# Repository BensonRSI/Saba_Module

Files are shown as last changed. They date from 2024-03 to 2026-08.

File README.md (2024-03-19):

# Saba_Module
Replacement for a game -module for the SABA Videoplay console

SABA Videoplay is a gaming console connected to a TV-set from the mid 1970s 
( also know as "The Channel F" (initially named Fairchild Video Entertainment System) )
see : https://channelf.se/veswiki/index.php?title=Main_Page or 
https://en.wikipedia.org/wiki/Fairchild_Channel_F

The replacement module consist of a Raspberry RP2040 microcontroller ( + a levelshifter for 3.3 / 5 V conversion ) 
that emulates an F3851 adressdecoder IC and holds the ROMs and additional RAM for the programms.

It samples the module extension port on a high rate and implements the statemachine, that will do the generation of the programm-counter and adress-generator.
To archieve a high sample-speed these parts arm written in ARM assembler ( thumb ) and running exclusivly on core 1

The first core does some convenience functions. You can connect through the USB-line, with a serial terminal on 115200 and get a little menu to 
diplay the memory, load different ROMs from the build-in flash or upload ROMs with xmodem-protocol.

## How to build

Using vscode, you can either use a codespace on github or use "reopen in container" , which wil install all neccessary tools and submodules.

Open a new terminal and simply type "make" . This is a wrapper to call the cmake and build the binary.

## How to download

connect an USB-cable. Enter Firmware upload by holding the button when connecting.

type "make go" this will build and upload the firmware.

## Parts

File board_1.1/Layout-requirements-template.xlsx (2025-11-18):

XXXX Project - PCB Layout Requirements
PCB Thickness (Default value:1.6mm) |  |  | Component Sides (Top/Bottom/Both sides) |  |  | These parameters are required if using impedance control or ordering a high-power PCB
PCB Layer Count |  |  | PCB Dimensions
Inner Layer Copper Weight |  |  | Outer Layer Copper Weight
Desired EDA Software (Rec: EasyEDAPro) |  |  | Software Version
Power Capacity | Net Name | Voltage (V) | Current (A) | Comment |  | Mandatory. Trace widths and spacings are chosen taking into account the voltage and current capacity requirements.
Impedance Control (Single-Ended) | Net Name |  | Impedance |  | Comment | Optional. Specify which nets need impedance control and their respective impedance targets.
Impedance Control (Differential) | Net Name |  | Impedance |  | Comment
Comments
Silkscreen Information |  | Font Size |  | Comment

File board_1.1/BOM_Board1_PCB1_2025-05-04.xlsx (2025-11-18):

No. | Quantity | Comment | Designator | Footprint | Value | Manufacturer Part | Manufacturer | Supplier Part | Supplier
1 | 1 | BAT20JFILM | D1 | SOD-323_L1.8-W1.3-LS2.5-RD |  | BAT20JFILM | ST(意法半导体) | C155590 | LCSC
2 | 1 | CSCC118-0602A002C1AC | H1 | HDR-SMD_6P-P1.00-V-F-S2.9_1 |  | CSCC118-0602A002C1AC | GREENCONN(格康) | C7434515 | LCSC
3 | 1 | 330Ω | R1 | R0805 | 330Ω | WR08X331JTL | Walsin(华新科) | C163990 | LCSC
4 | 1 | 3.3kΩ | R2 | R0805 | 3.3kΩ | WR08X332JTL | Walsin(华新科) | C163986 | LCSC
5 | 1 | RP2040-Plus | U1 | LCC-40_L51.0-W21.0-P2.54-BL_RP2040-BASED |  | RP2040-Plus | Waveshare(微雪电子) | C5374681 | LCSC
6 | 1 | SN74LVC16245ADGGR | U2 | TSSOP-48_L12.6-W6.2-P0.50-LS8.1-BL |  | SN74LVC16245ADGGR | TI(德州仪器) | C7824 | LCSC

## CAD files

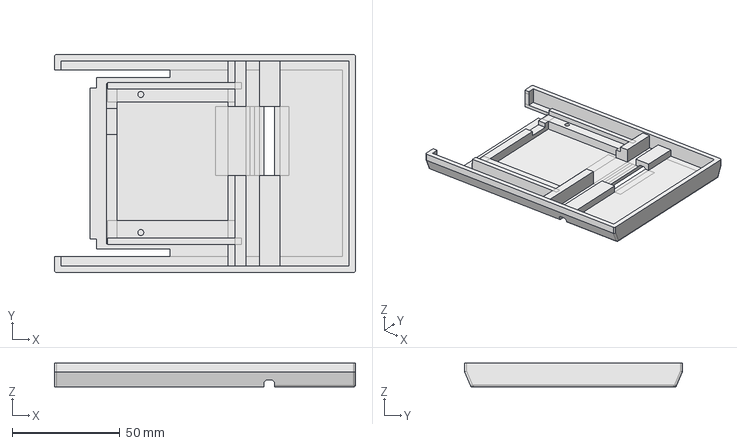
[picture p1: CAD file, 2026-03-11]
case/Case_unten_v3.FCStd
139.5 x 101.0 x 11.1 mm

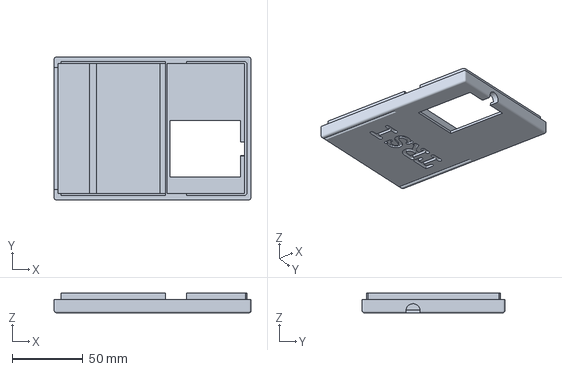
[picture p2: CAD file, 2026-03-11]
case/Case_oben_v2-Chamfer.3mf
139.5 x 101.0 x 14.0 mm

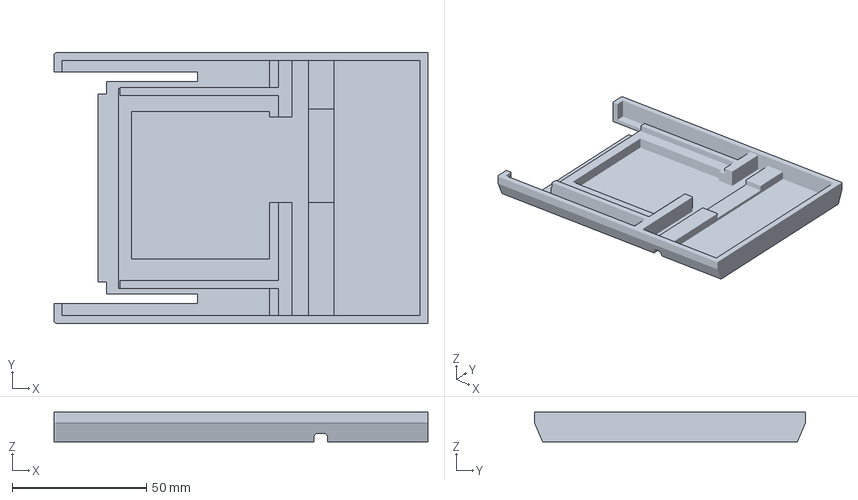
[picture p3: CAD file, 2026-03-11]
case/Case_unten_v2-Fillet001.3mf
139.5 x 101.0 x 11.1 mm

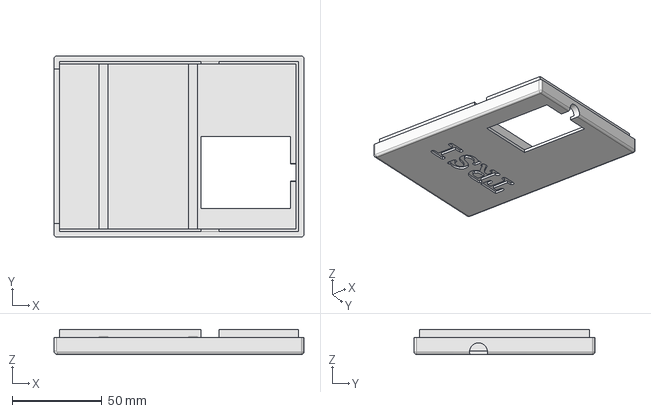
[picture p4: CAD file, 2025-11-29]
case/Case_oben.FCStd
139.5 x 101.0 x 14.0 mm

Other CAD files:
case/Case_oben-Fusion002.3mf
case/Case_unten-Cut003.3mf
case/Case_oben-Cut005.3mf
case/Case_unten_v2.FCStd
case/Case_unten.FCStd
case/Case_unten-Fillet001.3mf

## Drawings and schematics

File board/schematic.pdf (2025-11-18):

2DIR 24 2OE# 25 2A8 26 2A7 27 GND 28 2A6 29 2A5 30 VCC 31 2A4 32 2A3 33 GND 34 2A2 35 2A1 36 1A8 37 1A7 38 GND 39 1A6 40 1A5 41 VCC 42 1A4 43 1A3 44 GND 45 1A2 46 1A1 47 1OE# 48

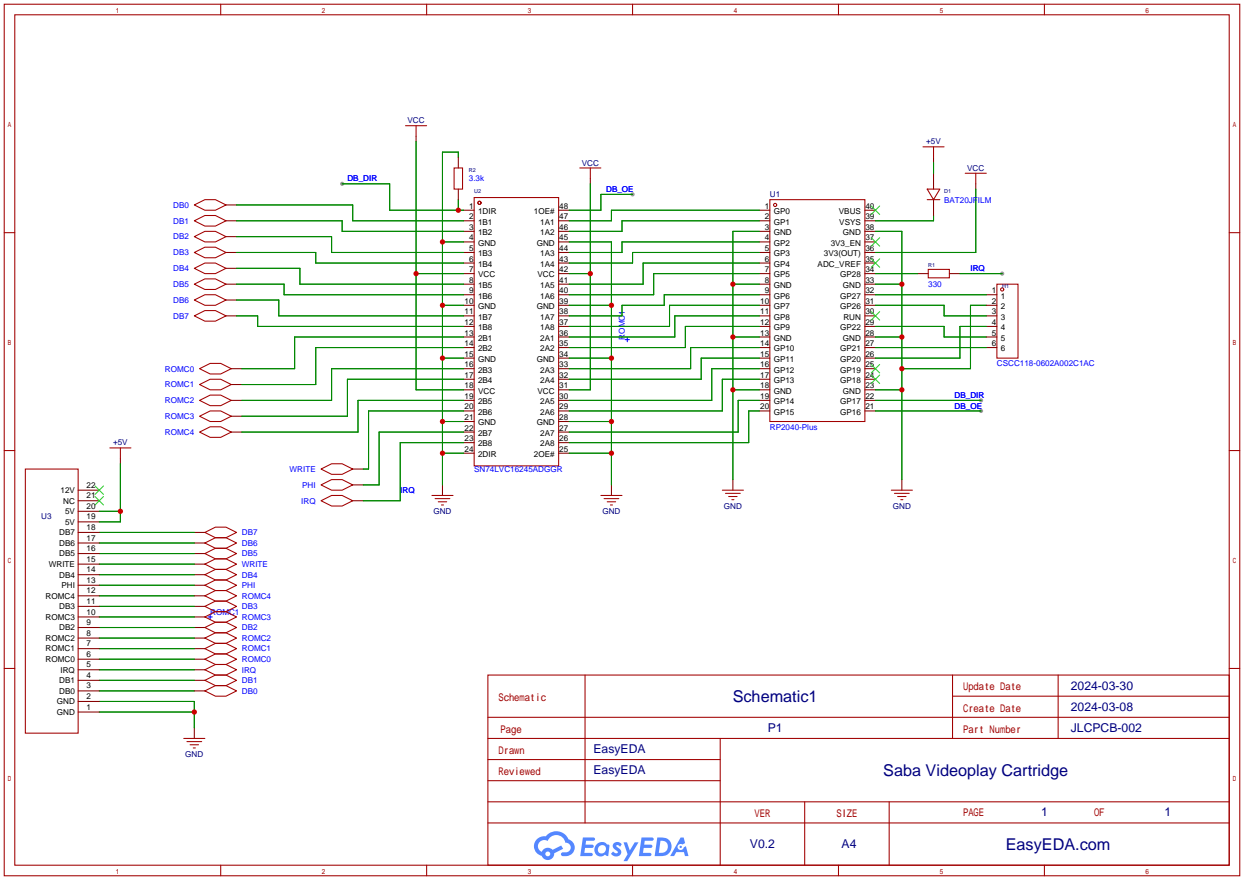
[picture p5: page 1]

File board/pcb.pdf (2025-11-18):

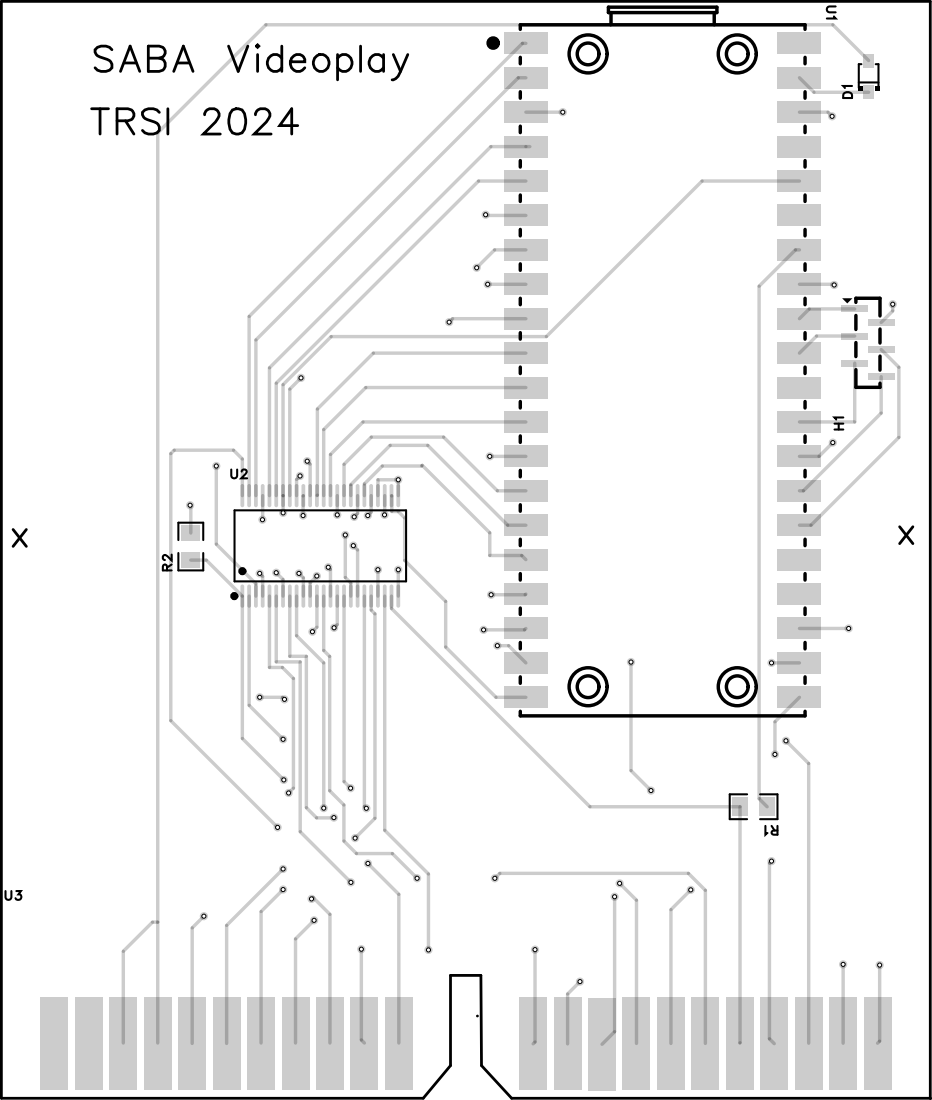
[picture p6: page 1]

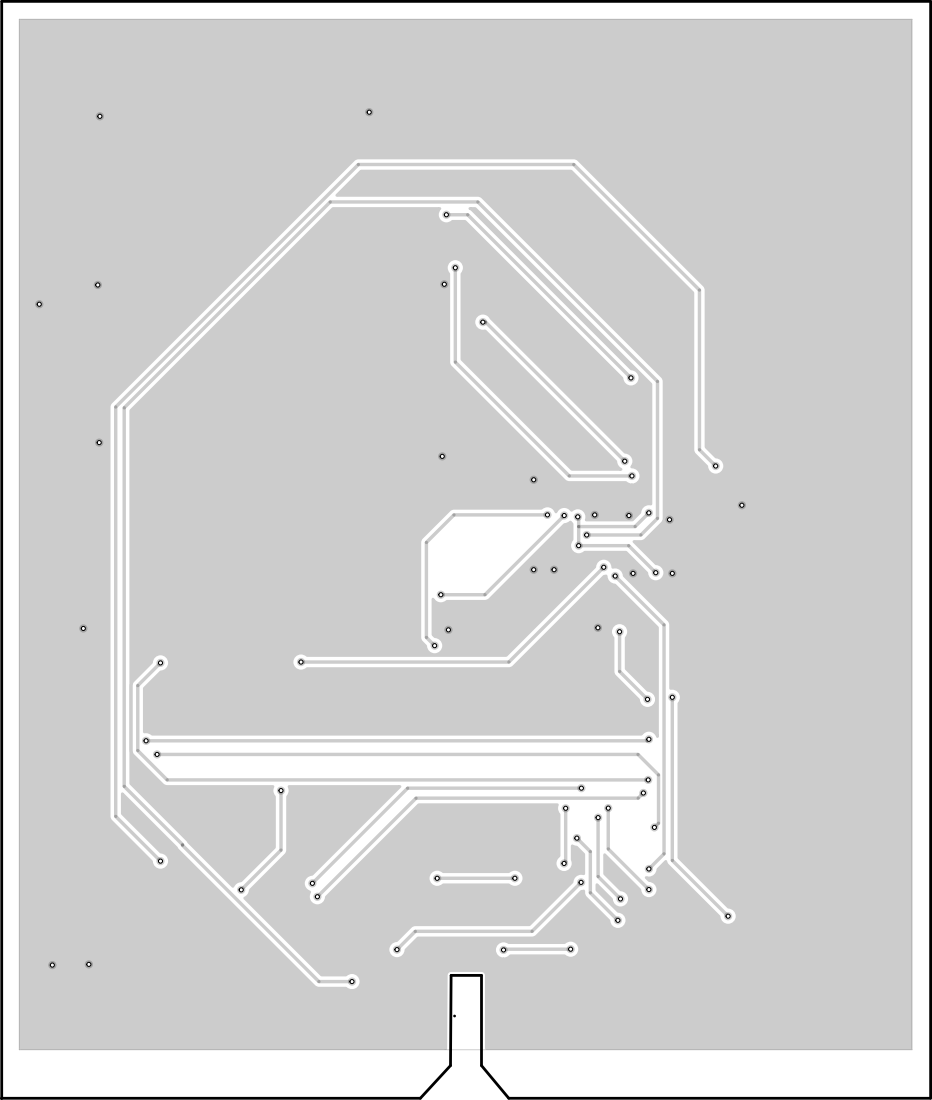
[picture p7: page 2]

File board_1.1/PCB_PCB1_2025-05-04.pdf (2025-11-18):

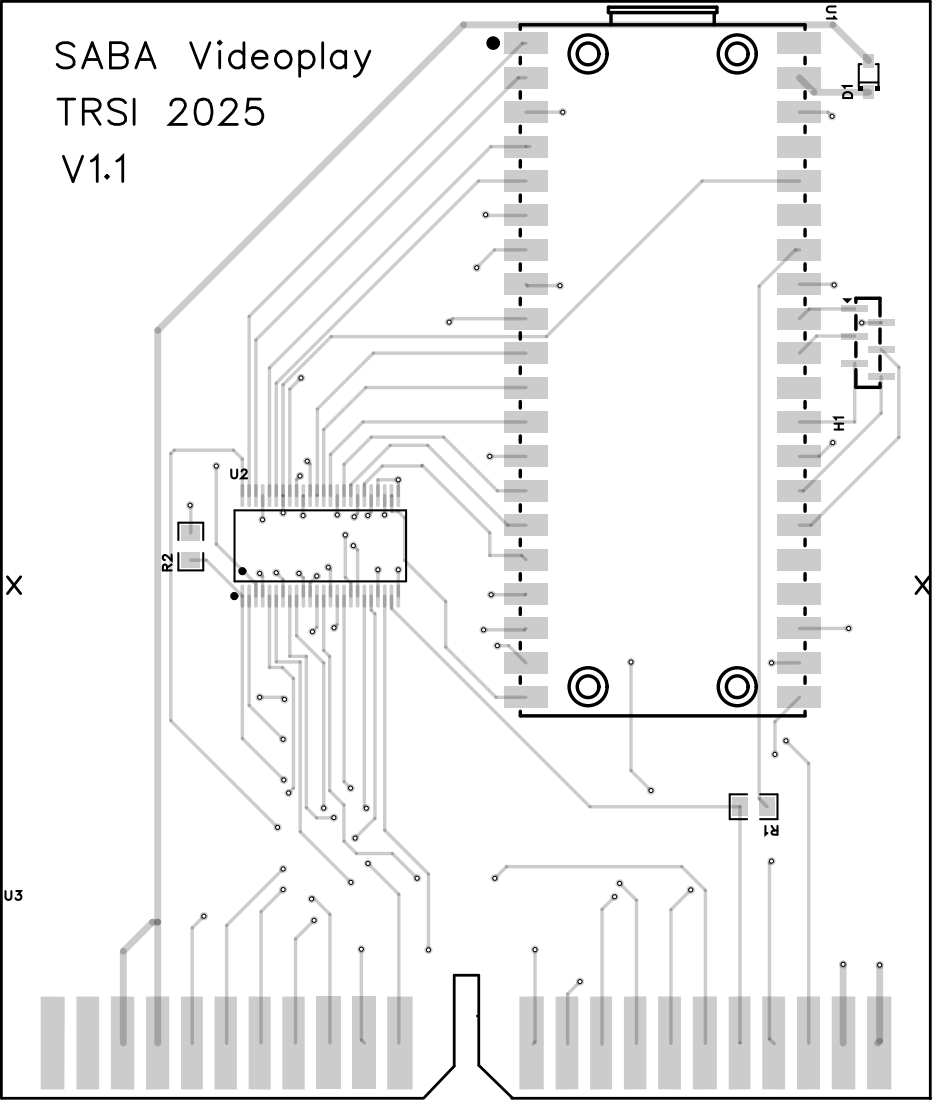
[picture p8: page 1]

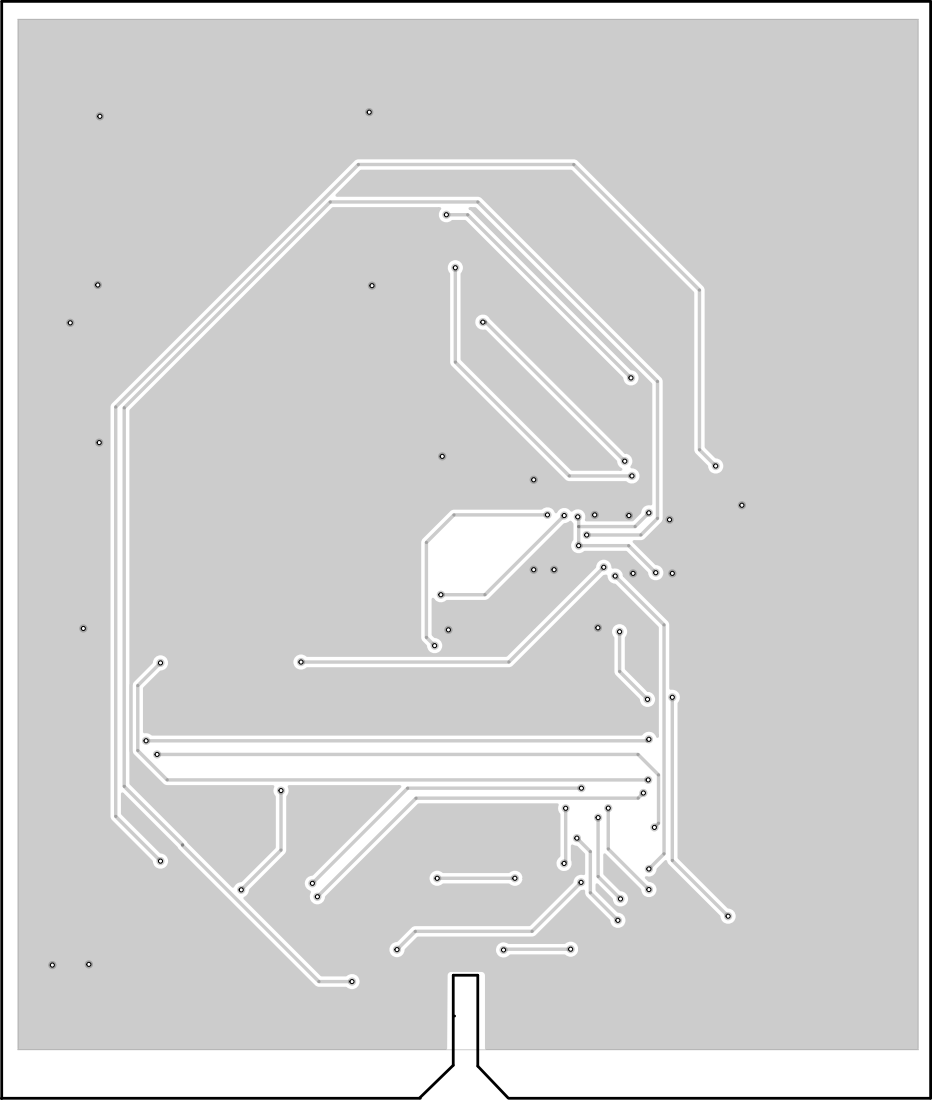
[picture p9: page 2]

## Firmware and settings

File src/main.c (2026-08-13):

/**
 * Copyright (c) 2024 Benson ( Olli )
 * SPDX-License-Identifier: GPL-3.0-or-later
 *
 *  This is part of the Saba_Module replacement for the Saba Videoplay console
 */

#include <time.h>
#include <stdio.h>
#include <ctype.h>
#include <string.h>

// #include "rp2040_purple.h"
#include <pico/stdlib.h>
#include <pico/util/queue.h>
#include <pico/multicore.h>
#include <pico/platform.h>
#include <pico/binary_info.h>
#include <hardware/vreg.h>   // Voltage control for overclocking
#include <hardware/clocks.h> // Clock control for overclocking

#include "bus.h"
#include "common.h"
#include "flash_store.h"

int main()
{
   // setup UART
   stdio_init_all();
   console_set_crlf(true);

#if 1
   // give some time to connect to console
   sleep_ms(2000);
#endif

#if 0
   vreg_set_voltage(VREG_VOLTAGE_1_30);
   sleep_ms(1);
   if (!(SET_CLOCK_FAST))
   { // 428000 is known to work on some devices
      // blink_code(BLINK::OVERCLOCK_FAILED);
      //     //panic("Overclock was unsuccessful");
      while (1)
         ;
   }
#endif
   // for toying with overclocking
   set_sys_clock_khz(133000, true); // 133 MHz is known to work on some devices

   // setup the bus and run the bus core
   multicore_launch_core1(bus_run);

   // run interactive console -> should never return
   console_run();

   return 0;
}

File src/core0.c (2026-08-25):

/**
 * Copyright (c) 2024 Benson ( Olli )
 * SPDX-License-Identifier: GPL-3.0-or-later
 *
 *  This is part of the Saba_Module replacement for the Saba Videoplay console
 */

#include <ctype.h>
#include <stdbool.h>
#include <stdio.h>
#include <string.h>
#include <stdint.h>
#include <stdlib.h>

#include <pico/multicore.h>
#include <pico/stdlib.h>
#include <pico/util/queue.h>
#include <hardware/clocks.h>

#include "common.h"
#include "getaline.h"
#include "mcurses.h"
#include "hexedit.h"
#include "bus.h"
#include "demo.h" // default demo data
#include "xmodem.h"
#include "flash_store.h"

// #define TEST_PATTERN // Fill memory with test pattern instead of 0x00

extern uint8_t memory[EMULATED_MEMSIZE]; // 64 k for Rom + 64 k banked Rom
// the first 32 bytes of the memory are used as IO-Ports
// The addresses are used for timer and IRQ-control and bank switching
// bit0-3 : IRQ control: 00=disable, 01=enable timer IRQ, others reserved
// bit4: timer start/stop
#define ICR_OFFSET_ADR 0xa
#define IRQ_CTRL_DISABLE 0
#define IRQ_CTRL_MASK 0x03 // for further use ,bit 1+2
#define IRQ_CTRL_ENABLE_TIMER_IRQ 3
#define IRQ_CTRL_ENABLE_EXT_IRQ 2

// this defines a 8-bit timer val, running at 38400 Hz
// with a prescaler od 31 , so 1 timer tick is 26 us *31
// a value of 0xff means timer stopped
// with a maximum Timer Tick of 0xfe, this means a maximum timer value of 0xfe * 806 = 204.724 us = 204 ms

#define IRQ_VECTOR_LOW_ADR 0x8
#define IRQ_VECTOR_HI_ADR 0x9
#define TIMER_VAL_ADR 0xb
#define ROM_BANK_ADR 0xc
#define TIMER_STOP 0xff
#define TIMER_CLOCK_MULTIPLIER 806 // 38400 Hz timer clock * 31  , so 1 timer tick = 806 us

extern volatile uint8_t reset_triggered;
extern volatile uint8_t irq_triggered;

uint8_t current_bank;
uint8_t upload_memory[0x10000 - 0x800 + BANK_SIZE * EXTENSION_BANKS]; /* Maximum size we can use = 64 k +62k*/
uint8_t *shadow_rom = &upload_memory[BANK_START_ADDRESS];             /* Shadow copy of the ROM when bank switching*/
#ifdef DEBUG_STATES
extern volatile uint8_t debug_val[18000];
int trace_dump = 0;
uint16_t print_buffer[2000];
#endif

bool console_crlf_enabled;
void debug_clocks();

// default functions are RAM access functons by pointers
uint8_t peekModuleMemory(uint16_t address)
{
   uint8_t *p;
   return memory[address];
}
void pokeModuleMemory(uint16_t address, uint8_t value)
{
   uint8_t *p;
   memory[address] = value;
}

uint8_t (*FunctionPointer_readModuleMemory)(uint16_t address) = peekModuleMemory;              // set default function
void (*FunctionPointer_writeModuleMemory)(uint16_t address, uint8_t value) = pokeModuleMemory; // set default function

/* For xmodem receive, we need to provide the HW specific functions*/
int _inbyte(int msec)
{

   int c = getchar_timeout_us(msec * 1000);
   if (c == PICO_ERROR_TIMEOUT)
   {
      return -1;
   }
   return c;
}
void _outbyte(unsigned char c)
{

   putchar(c);
}

void console_set_crlf(bool enable)
{
   uart_set_translate_crlf(uart0, enable);
   console_crlf_enabled = enable;
}

void fill_ram(uint8_t val)
{
#ifndef TEST_PATTERN
   memset(memory, val, EMULATED_MEMSIZE);
#else
   for (uint32_t i = 0; i < EMULATED_MEMSIZE; i += 2)
   {
      memory[i + 1] = i / 2;
      memory[i] = (i >> 8);
   }
   printf("Memory filled with test pattern\n");
#endif
}

// Use alarm 0
#define ALARM_NUM 0
#define ALARM_IRQ TIMER_IRQ_0

static void alarm_irq(void);
int timer_running = 0;
int timer_val = 0;
int timer_val_actual = 0;
int timer_ticks = 0; // holds the value in uS for the next Timer IRQ

static void alarm_in_us(uint32_t delay_us)
{
   // Enable the interrupt for our alarm (the timer outputs 4 alarm irqs)
   hw_set_bits(&timer_hw->inte, 1u << ALARM_NUM);
   // Set irq handler for alarm irq
   irq_set_exclusive_handler(ALARM_IRQ, alarm_irq);
   // Enable the alarm irq
   irq_set_enabled(ALARM_IRQ, true);
   // Enable interrupt in block and at processor

   // Alarm is only 32 bits so if trying to delay more
   // than that need to be careful and keep track of the upper
   // bits
   uint64_t target = timer_hw->timerawl + delay_us;

   // Write the lower 32 bits of the target time to the alarm which
   // will arm it
   timer_hw->alarm[ALARM_NUM] = (uint32_t)target;
   timer_running = 1;
}

static void alarm_irq(void)
{
   // Clear the alarm irq
   hw_clear_bits(&timer_hw->intr, 1u << ALARM_NUM);

   // Trigger IRQ , if enabled
   if (memory[ICR_OFFSET_ADR] & IRQ_CTRL_ENABLE_TIMER_IRQ)
   {
      // this is done by Core1 , so we can sync to the write-pulse
      // set GPIO pin low to signal IRQ
      // gpio_clr_mask(IRQ_OUT_MASK); // IRQ requested
      irq_triggered = 1;
      // printf("Timer IRQ triggered\n");
   }
   // Retrigger
   // This is not the actual behaviour of a F3853, which will retrigger at maxmium value,
   // but that doesn't make any sense.
   alarm_in_us(timer_ticks);
}

static void alarm_cancel(void)
{
   // Disable the interrupt for our alarm (the timer outputs 4 alarm irqs)
   hw_clear_bits(&timer_hw->inte, 1u << ALARM_NUM);
   // Disable the alarm irq
   irq_set_enabled(ALARM_IRQ, false);
   gpio_set_mask(IRQ_OUT_MASK); // IRQ requested

   timer_running = 0;
}
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

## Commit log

2024-03-19 Changed header with correct projectnaming
    [bus.h, core0.c, core1.c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]
2024-04-01 workaround timing, works with romreader
    [core0.c, core1.c]
2024-04-05 make assembler happy
2025-11-18 reading works fine, writing so lala
    [BOM_Board1_PCB1_2025-05-04.xlsx, Layout-requirements-template.xlsx, PickAndPlace_PCB1_2025-05-04.xlsx]
2025-11-20 Xmodem upload, 2800Ram fix
    [core0.c, core1.c]
2025-11-20 sabamon: fix end of func lines
    [6502.c]
2025-11-29 Added IRQ logic
    [Case_oben-Cut005.3mf, Case_oben-Fusion002.3mf, Case_oben.FCStd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]
2025-11-30 Port 8-F for timer / irq
2025-11-30 fixed Port 8-F for timer / irq
2025-11-30 fixed IRQ-pin setting
2026-03-11 Added flash-routines , but removed overclock
    [Case_oben_v2-Chamfer.3mf, Case_unten_v2-Fillet001.3mf, Case_unten_v2.FCStd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]
2026-08-20 Timer Tabellen fix
2026-08-25 switch off testpattern#
